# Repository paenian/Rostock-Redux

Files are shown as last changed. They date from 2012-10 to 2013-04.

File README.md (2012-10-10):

Rostock-Redux
=============

3d printer derived from rostock, using parameterized code.

I really like the looks and functionality of the rostock printer, but the code isn't very parametric.  This is my attempt to re-do it well.

Robot is sized for M4 screws and nut traps almost everywhere.

Major Vitamins:<br>
6 each of 6mm x 300mm square carbon fiber tubes for the arms<br>
6 each of 10mm x 1000mm steel rods for the vertical travel.<br>
3 each synchromesh pulleys<br>
6 meters synchromesh (from Standard Drive Products)<br>
<br>
Smooth rod offset is 225mm.<br>
<br>
Paul<br>

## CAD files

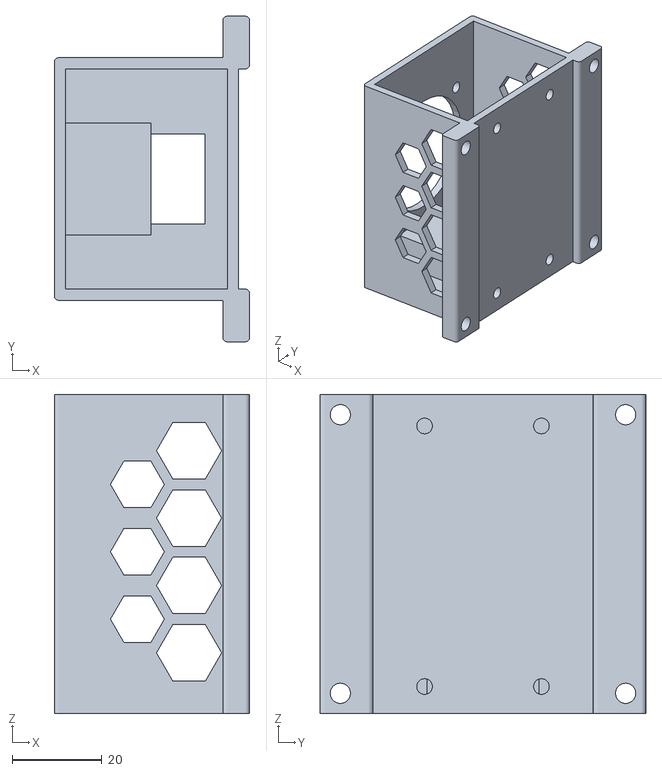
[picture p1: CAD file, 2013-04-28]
converterbox_40mm.stl
43.5 x 72.5 x 71.0

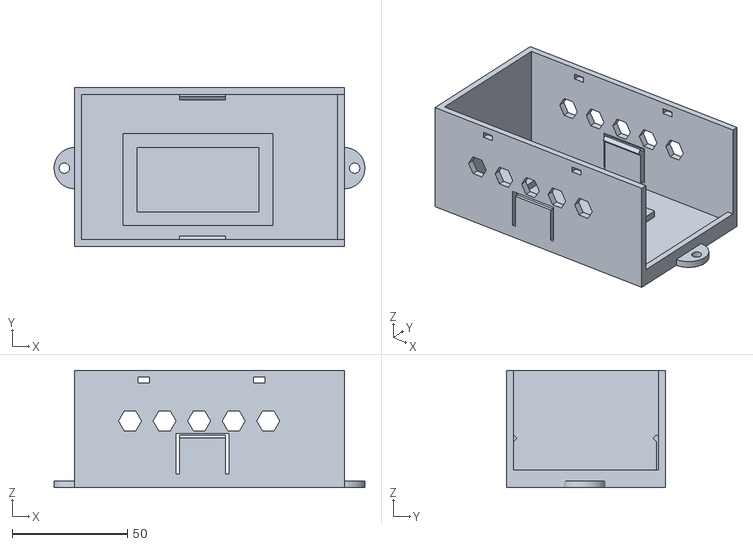
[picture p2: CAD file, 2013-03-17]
arduinobox.stl
135.0 x 69.0 x 51.0

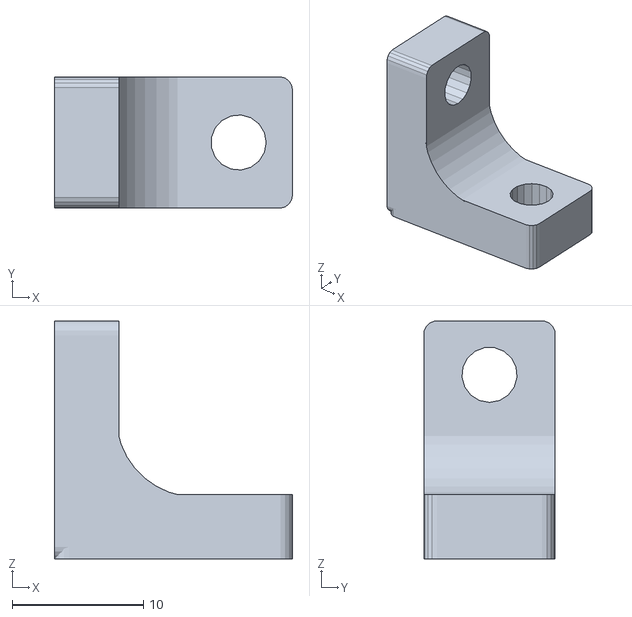
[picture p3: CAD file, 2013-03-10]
psmount.stl
18.1 x 10.0 x 18.1

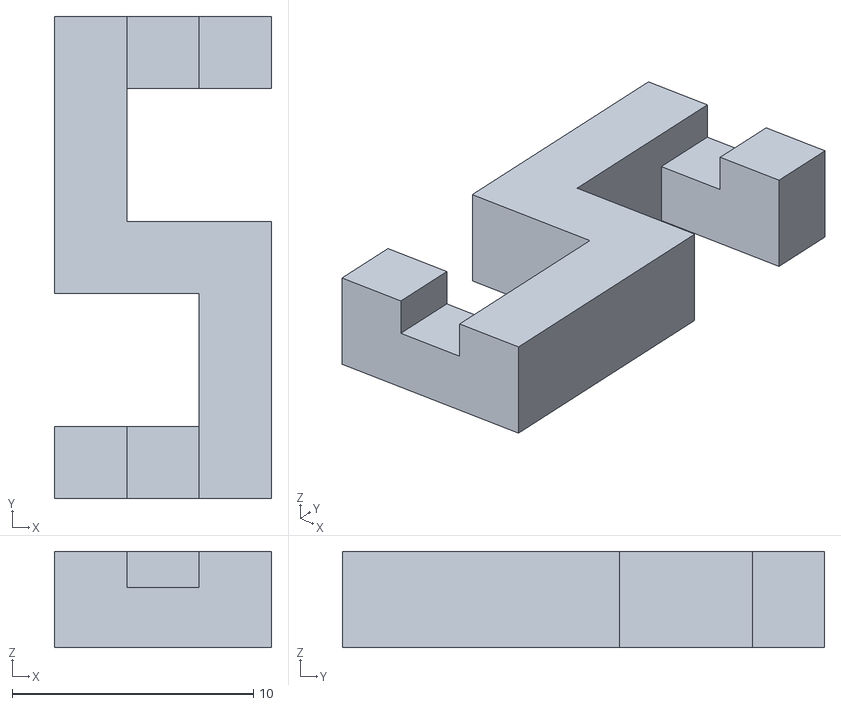
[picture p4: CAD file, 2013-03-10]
belt-tensioner.stl
9.00 x 20.0 x 4.00

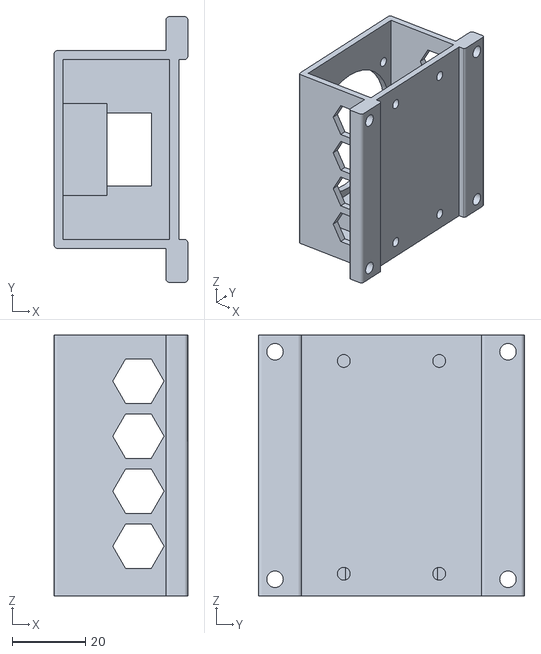
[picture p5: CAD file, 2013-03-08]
converterbox.stl
36.5 x 72.5 x 71.0

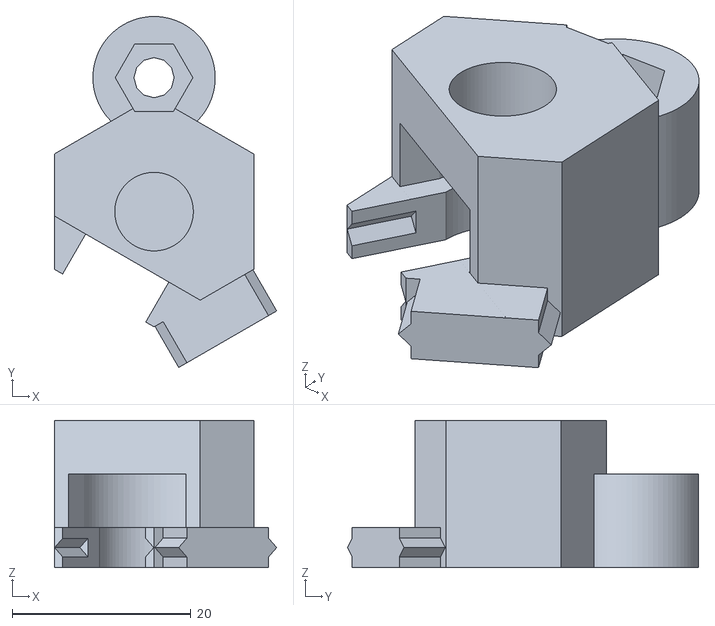
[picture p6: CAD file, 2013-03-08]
hotend_arm.stl
24.9 x 39.3 x 16.5

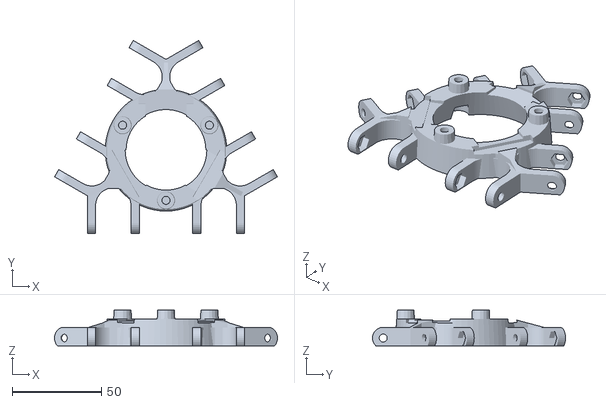
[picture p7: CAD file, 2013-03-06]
platform.stl
124.6 x 107.9 x 19.9

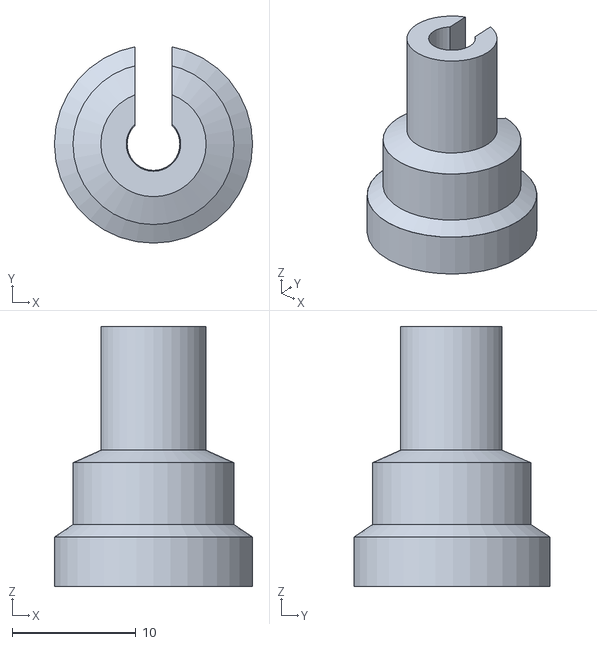
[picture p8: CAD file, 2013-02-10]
tubeguide.stl
16.0 x 15.8 x 21.0

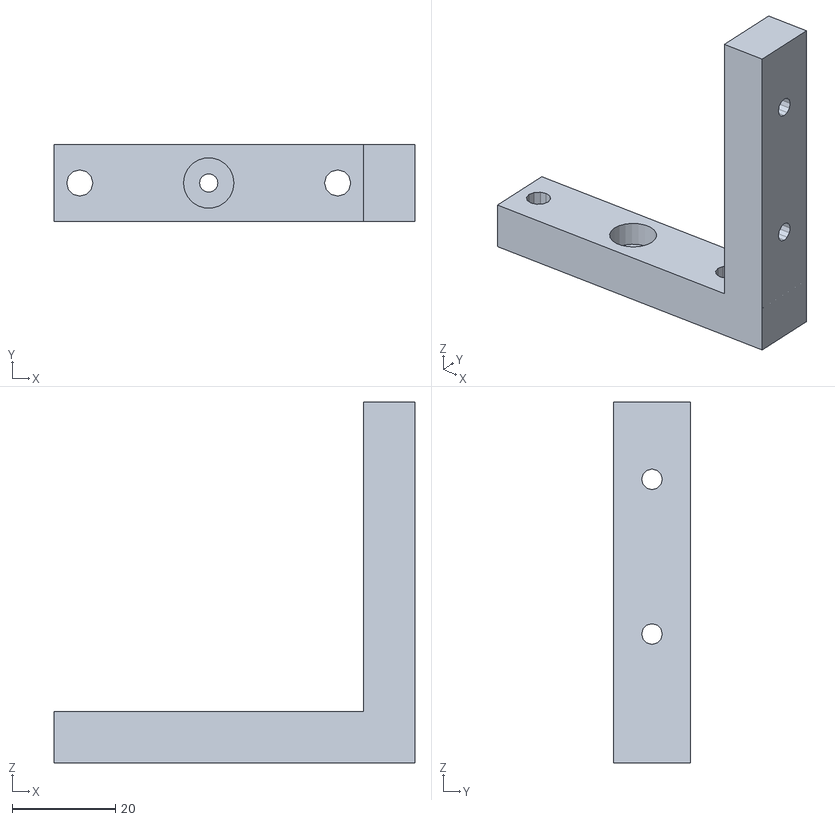
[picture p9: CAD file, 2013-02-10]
qubd_bowden_mount_3mm.stl
70.0 x 15.0 x 70.0

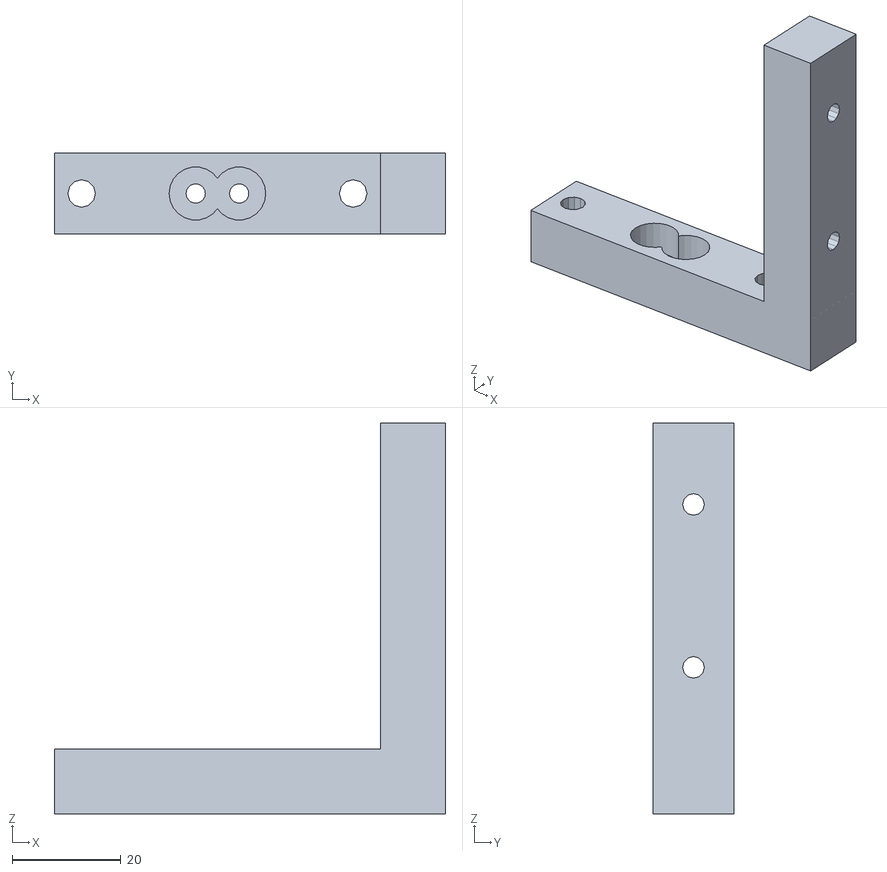
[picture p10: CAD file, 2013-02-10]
qubd_bowden_mount.stl
72.0 x 15.0 x 72.0

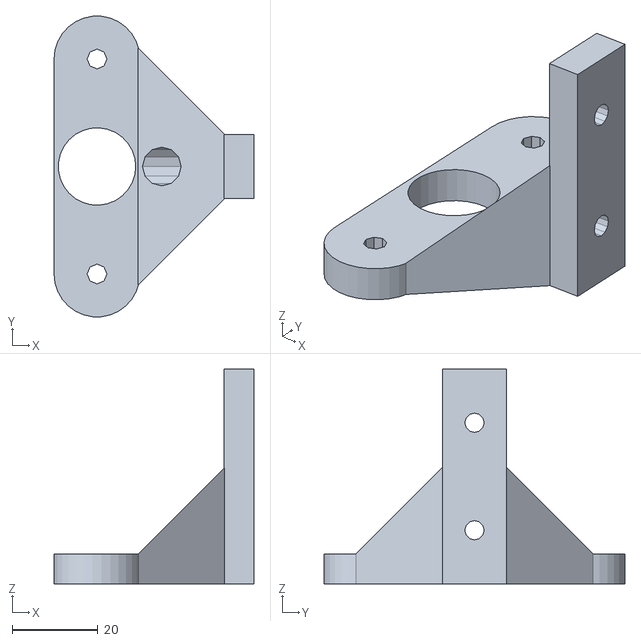
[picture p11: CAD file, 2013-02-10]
wade_mount.stl
46.5 x 69.9 x 50.0

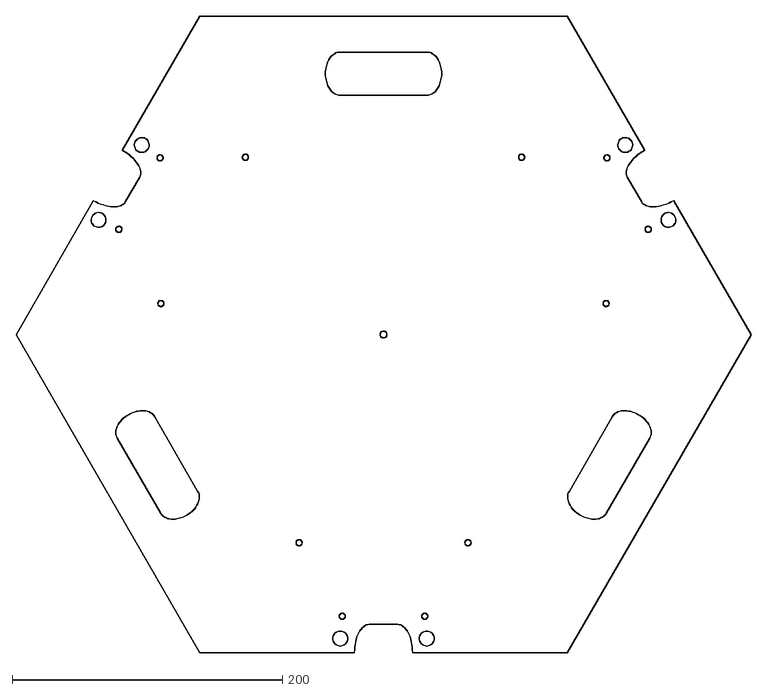
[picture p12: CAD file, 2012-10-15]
hexagon.dxf
543.9 x 471.0

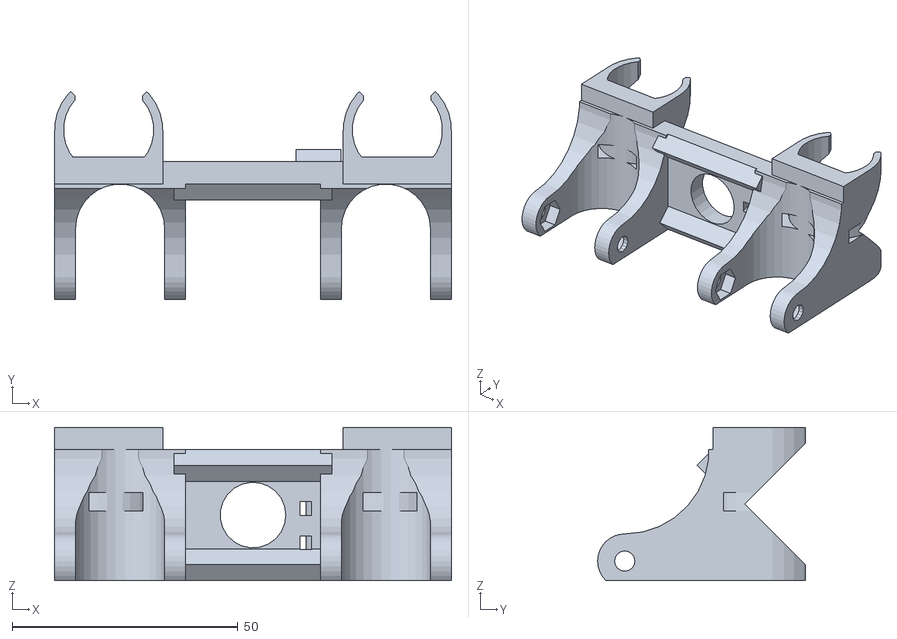
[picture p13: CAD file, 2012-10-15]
carriage.stl
88.0 x 46.1 x 34.0

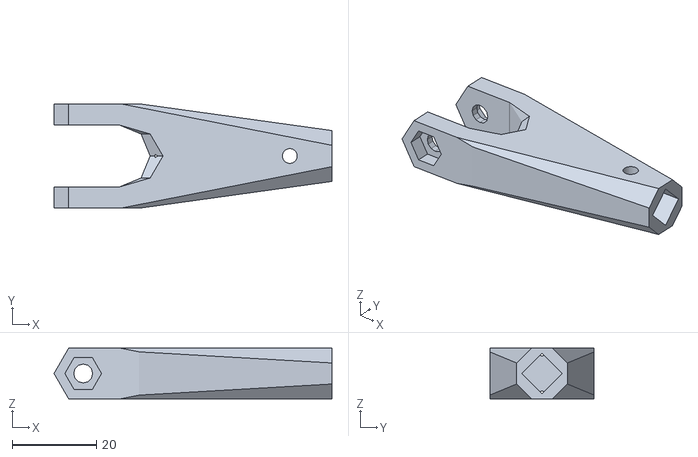
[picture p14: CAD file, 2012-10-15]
jaws.stl
65.9 x 24.7 x 12.0

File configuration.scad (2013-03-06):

rodSize  = 10;	//10 or 8; sets linear bearing size as well.
rodSeparation = 64;	//how far between rod centers
wall = 5;	//general wall thicknesses
boltSize = 4;	//3 for m3, 4 for m4
wingLength = rodSeparation;	//how long the wing supports are for the motor
				//and idler mounts.

//generic slop specs
rodSlop  = 1.0;	//how much bigger to make smooth rod holes
boltSlop = 0.5;	//how much bigger to make bolt holes
nutSlop  = 0.6;	//how much bigger to make nut holes
beltSlop = .5;	//synchromesh cable
jointSlop = 1.0;	//how much space around the joint
			//the joint itself isn't slopped, the parts that join to it are.

m8Dia = 8+boltSlop;
m8Rad = m8Dia/2;
m8NutDia = 15+nutSlop;
m8NutRad = m8NutDia/2;

nutDia = 8.1+nutSlop;
nutRad = nutDia/2;
boltDia = 4+boltSlop;
boltRad = boltDia/2;
nutHeight = 3.3;
washDia = 9+nutSlop;
washRad = washDia/2;

m3NutDia = 6.1+nutSlop;
m3NutRad = m3NutDia/2;
m3BoltDia = 3+boltSlop;
m3BoltRad = m3BoltDia/2;

//lm10uu specs
lm_dia = 20;
lm_height = 30;
lmMountSize = lm_dia+4;


//joint specs
tubeDia = 6;
jointHeight=boltSize*2+2;
jointInner=boltSize*2 / cos(30)+boltSize+boltSlop;  //small side of joint - clamped by the jaw
jointOuter=boltSize*2 / cos(30)+boltSize+boltSlop+wall;  //large side of joint, clamped by carriage & platform
mountWidth = jointOuter+jointSlop+nutRad+wall;
jointOffset = mountWidth/2+5;
jointSeparation=rodSeparation+lmMountSize-mountWidth; //separation between rod centers - used to align carriage & platform

//carriage specs
beltPitch = 3.81;


//platform specs
platform_thickness = 15;
platform_hinge_offset = 21;
bolt_ring_rad = 28;

//motor/idler specs
idlerShaft = 4.5;
motorShaft = 12.5;
motorMin = 12.5;
motorMax = 16.5;

tabGap = 1;
tabWidth = 6;

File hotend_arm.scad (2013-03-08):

include <configuration.scad>
use <carriage.scad>

center_rad = 22;

//this is for a makergear groovemount
hotend_outer_rad = 15.875/2;
hotend_inner_rad = 6;
hotend_rad = 13;

top_thickness = 6;
groove_thickness = 4.5;
groove_length = 6.75;

wedge_factor = 1.25;	//decrease this to make the slot wider, and the hotend easier to insert
groove_slot_width = hotend_inner_rad*2-wedge_factor;
top_slot_width = hotend_outer_rad*2-wedge_factor/2;

//this is for the threaded coupler
coupler_inner_rad = 4.4;
coupler_height=6;

layer_height=.2;

slot_lock=1.6;

$fn=72;

slop = .1;

//gray in the mounting holes and center space
translate([0,0,-.1])
%cylinder(r=center_rad, h=.2,center=true, $fn=32);

for (a = [0:2]) {
  rotate(a*120){
    translate([0, bolt_ring_rad, -.1])
    %cylinder(r=boltRad, h=.2, center=true, $fn=12);

    translate([0, hotend_rad, -.1])
    rotate([0,0,60])
    //translate([-10.5,0,0])
    {
      %cylinder(r=hotend_outer_rad, h=1, center=true, $fn=36);
      %cylinder(r=hotend_inner_rad, h=2, center=true, $fn=36);
    }
  }
}

module hotend_arm(){
  difference(){
    union(){
      //bolt mount
      translate([0,bolt_ring_rad,0])
      cylinder(r=nutRad+wall/2,h=groove_thickness+top_thickness-.01);
      
      translate([0,hotend_rad,0])
      rotate([0,0,30]){
        //hotend mount
        cylinder(r=hotend_rad-slop,h=groove_thickness+top_thickness+coupler_height, $fn=6);
        
        //alignment peg
        translate([0,(-hotend_rad+slop)*cos(30)-groove_thickness/2+slop+slop,groove_thickness/2]){
          cube([groove_slot_width-slop*2,groove_length-slop*2,groove_thickness],center=true);
          for(i=[0,1]){
            mirror([i,0,0])
            translate([(groove_slot_width-slop*2)/2,1,0])
            rotate([0,45,0])
            cube([slot_lock-slop,groove_length-slop*2+2,slot_lock-slop],center=true);
          }
        }
      }
    }

    //bolt hole
    translate([0,bolt_ring_rad,0]){
      translate([0,0,nutHeight])
      cylinder(r=nutRad,h=nutHeight+20, $fn=6);
      cylinder(r=boltRad,h=groove_thickness*2, center=true, $fn=12);
    }

    //hotend hole
    translate([0,hotend_rad,-.1])
    cylinder(r=hotend_inner_rad+slop,h=groove_thickness+.2);
    translate([0,hotend_rad,groove_thickness])
    cylinder(r=hotend_outer_rad+slop,h=top_thickness);

    //coupler mounting hole & slit
    translate([0,hotend_rad,groove_thickness+top_thickness+layer_height*2]){
      cylinder(r=coupler_inner_rad,h=8.1);
      rotate([0,0,150])
      *translate([-coupler_inner_rad/4,0,0])  //kill the slit... was screwing up threading
      cube([coupler_inner_rad/2,20,30]);
    }
    translate([0,hotend_rad,groove_thickness-.01])
    rotate([0,0,150])
    translate([-20,6,0])
    cube([40,10,30]);
    
    
    //slot for groove
    rotate([0,0,60])
    translate([0,hotend_rad/2,groove_thickness/2]){
      cube([hotend_rad*2,groove_slot_width,groove_thickness+.2],center=true);
      for(i=[0,1]){
          rotate([0,0,90])
          mirror([i,0,0])
          translate([(groove_slot_width-slop*2)/2,1-groove_length/2,0])
          rotate([0,45,0])
          cube([slot_lock,groove_length,slot_lock],center=true);
        }
    }

    //top slot
    rotate([0,0,60])
    translate([2,hotend_rad/2,groove_thickness+top_thickness/2])
    cube([top_slot_width,top_slot_width,top_thickness],center=true);

    //center bolt
    //cylinder(r=boltRad, h=20, center=true);
    //translate([0,0,groove_thickness/2]) cylinder(r=nutRad, h=20, $fn=6);
  }
}

module assembled(){
  for (a = [0:2]) {
    rotate([0,0,a*120])
    hotend_arm();
  }
}

//assembled();

hotend_arm();

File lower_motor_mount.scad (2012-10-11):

include <configuration.scad>
use <global_functions.scad>

//mount is printed upside-down to allow for nice wings.

//local variables
mrodDia = rodSize+rodSlop;
mrodRad = mrodDia/2;
mheight = 50;
mSlotCenter = (motorMin+motorMax)/2;
mSlotWidth = 3 +boltSlop;
mSlotLength = (motorMax - motorMin+mSlotWidth)*sqrt(2);
mnutHeight = nutRad/2;
mStiff = 3;
smoothRodOffset = 225;

module rodMountHoles(){
	for(i=[0:1]){
		translate([rodSeparation*i,0,0])
		mirror([1*i,0,0]){
			//rod holes
			cylinder(r=mrodRad, h=mheight,$fn=32);
		
			//bolt holes center
			translate([wall/2-1,-mrodDia/2-wall-wall-1,0])
			cylinder(r=boltRad, h=mheight, $fn=32);

			//bolt holes wing	
			translate([wall/2-1,-mrodDia/2-wall-wall,0])
			rotate([0,0,-120])
			translate([wingLength,0,0])
			cylinder(r=boltRad, h=mheight, $fn=32);
		}
	}
}

module rodMount(motor=true){
	union(){
		for(i=[0:1]){
			translate([rodSeparation*i,0,0])
			mirror([1*i,0,0]){
				//rod clamps
				//rotate([0,0,30])
				rod_pressure_mount(mrodDia, wall, mheight, clamp=boltSize);
	
				//platform mounts inner
				translate([wall/2-1,-mrodDia/2-wall-wall-1,0])
				hex_nutmount(boltSize,boltSize-1,mnutHeight*3, false);

				//platform mounts wing	
				translate([wall/2-1,-mrodDia/2-wall-wall,0])
				rotate([0,0,-120])
				translate([wingLength,0,0])
				hex_nutmount(boltSize,boltSize-1,mnutHeight*3, false);
				
				//wing supports
				translate([0,-mrodDia/2-wall-wall,0])
				rotate([0,0,-120])
				translate([-wall,-nutRad-wall,0])
				difference(){	
					cube([wingLength+wall+wall, wall, mheight]);
					
					translate([wall,-.5,mheight])
					rotate([0,atan((mheight-mnutHeight*2)/(wingLength+wall)),0])	
					cube([wingLength*2,wall+1,mheight]);

					translate([wingLength+wall+mnutHeight,0,mheight])
					rotate([90,0,0])
					scale([1,(mheight-wall-mnutHeight)/wingLength,1])
					cylinder(h=wall*4, r=wingLength,center=true,$fn=63);
				}
			}
		}

		//motor mount plate
		difference(){
			union(){
				translate([0,-mrodDia/2-wall,0])
				cube([rodSeparation,wall, mheight]);

				//stiffeners
				for(i=[0:2]){
					translate([rodSeparation/2,-mrodDia/2,(mheight/2-mStiff/sqrt(2))*i+mStiff/sqrt(2)])
					rotate([0,90,0])
					rotate([0,0,45])
					cube([mStiff,mStiff,rodSeparation-mrodDia],center=true);
				}

				//support for the idler bolt
				if(motor==false){
					translate([rodSeparation/2,-mrodDia/2,mheight/2])
					rotate([90, 0, 0])
					{
						translate([0,0,wall-.01])
						difference(){
							//idler shaft hole
							cylinder(r1=m8NutDia+2, r2=m8NutRad, h=m8NutRad);

							translate([0,0,.02])
							cylinder(r=m8NutRad, h=m8NutRad, $fn=6);
						}
					}
				}
			}
		
			if(motor){
				//center hole
				translate([rodSeparation/2,-mrodDia/2,mheight/2])
				rotate([90, 0, 0])
				{
					//motor shaft hole
					cylinder(r=motorShaft, h=mheight, center=true);
	
					//mounting holes
					for(i=[0:3]){
						rotate([0,0,90*i]){
							translate([mSlotCenter, mSlotCenter,0])
							rotate([0, 0, -45])
							cube([mSlotWidth, mSlotLength, mheight], center=true);
						}
					}
				}
			}else{
				//center hole
				translate([rodSeparation/2,-mrodDia/2,mheight/2])
				rotate([90, 0, 0])
				{
					//idler shaft hole
					cylinder(r=m8Rad, h=mheight, center=true);
					
					//washer area
					translate([0,0,-wall/2-.005])
					cylinder(r=motorShaft, h=wall, center=true);
				}
			}
		}
	}
}

//make the hex plate
module hexPlate(motor=true){
projection(){
	difference(){
		translate([0,0,wall/2])
		cylinder(r=(smoothRodOffset+wall+mrodRad)/cos(30), h=wall, center=true, $fn=6);
		echo("Hex flat-to-flat distance = ",(smoothRodOffset+wall+mrodRad)*2);
		echo("Hex point-to-point distance = ",(smoothRodOffset+wall+mrodRad)/cos(30)*2);
		cylinder(r=2.5,h=mheight,center=true,$fn=32);

		for(i=[0:2]){
			rotate([0,0,120*i]){
				//mounting holes
				translate([-rodSeparation/2,smoothRodOffset,-1])
				rodMountHoles();
			
				//drive cable slot
				for(j=[0:1]){
					mirror([j*1,0,0])
					translate([rodSeparation/2-wall-mrodDia-mrodRad,smoothRodOffset+wall+mrodRad,-1])
					scale([1,(2*wall+mrodDia)/mrodDia,1])
					cylinder(r=mrodDia, h=mheight, $fn=64);
				}
				translate([0,smoothRodOffset,-1])
				cube([2*wall+mrodDia,2*wall+mrodDia,2*wall+mrodDia],center=true);
				
				//handles
				rotate([0,0,60]){
					for(j=[0:1]){
						mirror([j*1,0,0])
						translate([rodSeparation/2,smoothRodOffset-(mrodDia+wall)*2,-1])
						scale([1,(wall+mrodDia)/mrodDia,1])
						cylinder(r=mrodDia, h=mheight, $fn=64);
					}
					translate([0,smoothRodOffset-(mrodDia+wall)*2,-1])
					cube([rodSeparation,(mrodDia+wall)*2,2*wall+mrodDia],center=true);
				}
			}
		}
	}
}
}

//place for printing
module printPlate(motor=true){
	translate([0,0,-.1])
	%cube([200,200,0.2], center=true);
	for(i=[0:2]){
		rotate([0,0,90])
		translate([-rodSeparation/2,45*i-wall*2,0])
		rodMount(motor);
	}
}

//rodMount(true);

//printPlate(false);
rotate([0,0,60])
hexPlate(true);
//translate([0,(smoothRodOffset+wall+mrodRad)*2+.25*25.4,0])
//hexPlate(false);

//rodMount(true);
//rodMountHoles();

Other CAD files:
motor_mount.stl
SynchromeshIdler.stl
idler_mount.stl
joint.stl
arduinobox.scad
belt-tensioner.scad
carriage.scad
converterbox.scad
functions.scad
global_functions.scad
jaws.scad
joint.scad
lmxuu_mount.scad
nuts_and_bolts.scad
platform.scad
psmount.scad
qubd_bowden_mount.scad
tubeguide.scad
wade_mount.scad

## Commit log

2012-07-30 Initial code commit - moter end completed.
    Finished the motor end, although I'll be modifying the file to produce
    the idler end as well.
    Default is a pressure-fit coupler, with bolts (nut traps) near the rod
    mounts and screw pockets for the stabilizer wings.
    [configuration.scad, functions.scad, global_functions.scad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]
2012-07-30 Added dependency
    functions.scad depends on the openscad default library
    nuts_and_bolts.scad - including it in the repo for convenience.
    [functions.scad, nuts_and_bolts.scad]
2012-07-30 Added ignore list.
    since I like to use VIM, and nobody needs to see the tilde files.
    [functions.scad]
2012-07-31 Minor edits.
    [configuration.scad, global_functions.scad, lower_motor_mount.scad]
2012-08-28 Updated config - bigger margins.
    [configuration.scad]
2012-08-28 More facets.
    [global_functions.scad]
2012-08-28 Screws for both mounts, fixed screw mount location
    [lower_motor_mount.scad]
2012-09-13 Updates - finalized motor mount, ready for printing.
    [configuration.scad, lower_motor_mount.scad]
2012-09-13 Added a snap-in LM10uu holder.
    The constants are guesses, I'll measure later.
    [lmxuu_mount.scad]
2012-09-24 Added idler (in motor mount), lmxuu mount tested
    lmxuu mounts clip in bearings, will add to carriage next.
    [configuration.scad, global_functions.scad, lmxuu_mount.scad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]
2012-09-24 Added carriage.
    Need to update the parallel mounts to be parametric/fit my rods.
    [carriage.scad, lmxuu_mount.scad]
2012-09-24 Fluffing it out
    Added bits from upstream, edited the carriage slightly, updated config.
    New additions have been modified to support square carbon fiber tubes.
    [carriage.scad, configuration.scad, jaws.scad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]
2012-09-27 Update joint.scad
    Updated to accept any size bolts, parametric based on config file.
    [joint.scad]
2012-09-27 Update configuration.scad
    Added joint configuration, plus a little organization.
    [configuration.scad]
2012-09-27 Update configuration.scad
    Updated config for jaws.
    [configuration.scad]
2012-09-27 Update jaws.scad
    Parametricized, configured to match the joint via configuration.scad. Meant to attach to a 6mm square carbon fiber rod, includes a set screw hole at the top.
    [jaws.scad]
2012-09-27 Update carriage.scad
    Fixed everything but the belt mount.
    [carriage.scad]
2012-09-27 Update configuration.scad
    Updated for platform configs.
    [configuration.scad]
2012-09-27 Update jaws.scad
    minor edits
    [jaws.scad]
2012-09-27 Update joint.scad
    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
    [joint.scad]
2012-09-27 Update platform.scad
    Modified to work with updated carriage. Semi-paramaterized, could use some cleanup.
    [platform.scad]
2012-09-30 Actually printing!
    Minor edits to pretty much all tolerances, due to clearance
    issues/printing etc. Should have an axis or three up soon.
    [carriage.scad, configuration.scad, jaws.scad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]
2012-10-01 Clearance added
    after printing, needed more clearance for the swing arms. Note that
    this changes the platform and joint as well - they'll need to be
    re-printed.
    [carriage.scad, configuration.scad]
2012-10-10 Update lower_motor_mount.scad
    Added the hexagonal lower plate. Will make it exportable as a DXF for lasercutting/printing soon.
    [lower_motor_mount.scad]
2012-10-10 Update lower_motor_mount.scad
    Now it draws two plates.
    [lower_motor_mount.scad]
2012-10-15 Added STLs
    whee
    [SynchromeshIdler.stl, carriage.stl, idler_mount.stl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]
2012-10-15 Added a DXF of the top/bottom plates
    whee, hexagon! Can be sized smaller, I mean it doesn't need to include
    the rod holes even, but I wanted it to be big and strong. I might
    modify the motor and idler mounts to mount vertical wood stabilizers
    behind them, make it uber strong.
    [hexagon.dxf]
2012-11-12 Added triple hotend mount, bugfix platform
    Haven't printed it yet, it'll fit a makergear extruder to a 1/8" NPT
    coupling for my bowden tube.
    [hotend_arm.scad, jaws.scad, platform.scad]
2012-11-21 Hotend mounts, and an adapter for qu-bd extruder.
    Hotend arm - print 3, a Makergear groovemount will snap in and then they
    puzzle-lock together for mounting on the platform.
    [hotend_arm.scad, platform.scad, platform.stl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]
2013-02-10 Been lax on commits.
    Several new updates, hostly around the mounting of various hotend
    solutions. Finally went with the AirTripper bowden, although I'll
    update that eventually - it flexes a bit too much for my liking.
    [hotend_arm.scad, hotend_arm.stl, qubd_bowden_mount.scad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]
2013-02-10 Added a guide for the Bowden tube
    Keeps the end of the tube vertical coming off of the extruder.
    [tubeguide.scad, tubeguide.stl]
2013-03-06 Beefed up the platform, added fan slots.
    The platform was too flexible. Additionally, this raises the hotends so
    that only the tips are below the platform.
    [configuration.scad, platform.scad, platform.stl]
2013-03-06 Upgraded platform, hotend arms
    The mounting holes are farther apart, more room for hotends, plus small
    fan mounts and stronger hotend holders.
    [configuration.scad, hotend_arm.scad, hotend_arm.stl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]
2013-03-06 Wrong rendering for the hotend arm
    whoops.
    [hotend_arm.scad, hotend_arm.stl]
2013-03-08 hotend arm edits
    Fixed so that you can use the screw connector to compress the hotend,
    locking it in place.
    [hotend_arm.scad, hotend_arm.stl]
2013-03-08 box for my 12->24v converter
    I don't know who made it, or where it came from. Sorry. It works
    great, though.
    [converterbox.scad, converterbox.stl]
2013-03-10 tiny m4 mounting brackets for power supply
    and some belt tensioners sized for synchromesh.
    [belt-tensioner.scad, belt-tensioner.stl, psmount.scad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]
2013-03-16 Made a box to mount my RAMPS.
    Ramps clips in, fan zip ties on top. Printing tonight, will update if
    it doesn't work.
    [arduinobox.scad, arduinobox.stl]
2013-03-17 updates... the clips were too low.
    [arduinobox.scad, arduinobox.stl]
2013-04-28 Updated the converter box for better airflow... after my converter overheated. Due to poor airflow.
    [converterbox.scad, converterbox_40mm.stl]
